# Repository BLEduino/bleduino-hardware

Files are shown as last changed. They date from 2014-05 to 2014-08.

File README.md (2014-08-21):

BLEduino Hardware
=================
Here you'll find all of the hardware design files related to the BLEduino and Shield-Shield.

* Bill of Materials - The full parts list used on the BLEduino and the Shield-Shield.
* Eagle - Schematic and PCB files for the BLEduino and Shield-Shield.
* Gerber - All of the Gerber files needed to produce your own BLEduinos or Shield-Shield.
* PDFs - PDF copies of the schematics and pcb including the individual layers.

These files are licensed under a [Creative Commons Attribution Share-Alike license](http://creativecommons.org/licenses/by-sa/2.5/).  That means you're allowed to modify, view, distribute, and remix any of the files for personal and comerical purposes as long as you credit the BLEduino and release your design files under the same or similar license.

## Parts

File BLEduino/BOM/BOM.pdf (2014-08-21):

# | Part | Q'ty | Description | Package | Pads | Mounting type | Vendor | Part No. | Brand | Descriptor

## BLEduino

1 | 3.3V Regulator | 1 | LP2985-33DBVR | SOT-23 | 5 | SMD | TI | 296-18476-1-ND | TI | U4
2 | 5V Regulator NCP1117-5 | 1 | NCP1117ST50T3G | SOT-223 | 4 | SMD | ON | NCP1117ST50T3GOSCT-ND | ON | U2
3 | 3x1 Male Headers | 1 | | 0.1" | 0 | SMD | | 929400E-01-03-ND | | JP4
4 | 1x14 Male Headers | 2 | | 0.1" | 0 | SMD | | 929400E-01-14-ND | | JP1, JP3
5 | Anti-Static Varistor | 2 | CG0603MLC-05E | 0603 | 2 | SMD | Bourns Inc. | CG0603MLC-05ECT-ND | Bourns Inc. | Z1, Z2
6 | ATMega32u4 | 1 | ATMEGA32U4-MU | QFN-44 | 45 | SMD | Atmel | ATMEGA32U4-MU-ND | Atmel | U1
7 | ATMega328P | 1 | ATMEGA328P-MUR | QFN-32 | 33 | SMD | Atmel | ATMEGA328P-MURCT-ND | Atmel | U3
8 | BLE Controller | 1 | NRF8001-R2Q32-T | QFN-32 | 33 | SMD | Nordic Semiconductor | 949-NRF8001-R2Q32-T | Nordic Semiconductor | NRF8001
9 | BALUN | 1 | 2450BM14A0002T | 0603 (6 pin) | 6 | SMD | Johanson Technology | 44W4473 | Johanson Technology | B1
10 | CAP 100n Ceramic | 10 | 0.1UF 25V 5% 0402->X7R | 0402 | 2 | SMD | | 587-1456-1-ND | | C1, C2, C6, C9, C10, C11, C18, C22, C30, C31
11 | CAP 15pF Ceramic | 4 | 15PF 16V 5% 0402->50V | 0402 | 2 | SMD | | 311-1017-1-ND | | C20, C21, C28, C29
12 | CAP 1nF Ceramic | 1 | 1000PF 10V 10% 0402->50V | 0402 | 2 | SMD | | 311-1036-1-ND | | C27
13 | CAP 1u Ceramic | 3 | 1UF 16V 10% 0402->10V X5R | 0402 | 2 | SMD | | 445-4978-1-ND | | C5, C4, C7
14 | CAP 1uF Ceramic | 2 | 1UF 16V 10% 0603->X5R | 0603 | 2 | SMD | | 311-1372-1-ND | | C16, C24
15 | CAP 2.2nF Ceramic | 1 | 2200PF 25V 5% 0402->50V X7R | 0402 | 2 | SMD | | 490-6359-1-ND | | C23
16 | CAP 22p Ceramic | 4 | 22PF 16V 5% 0402->0.25PF 50V | 0402 | 2 | SMD | | 311-1018-1-ND | | C12, C13, C32, C33
17 | CAP 22u Tantalum (Polarized) | 2 | CAP TANT 22UF 25V 1206->10V | 1206 | 2 | SMD | | 511-1465-1-ND | | C3, C14
18 | CAP 33nF Ceramic | 1 | 0.033UF 10V 10% 0402->16V | 0402 | 2 | SMD | | 1276-1555-1-ND | | C17
19 | CAP 2pF Ceramic | 1 | 2.0pF 10V 5% 0402->0.25PF 50V | 0402 | 2 | SMD | | | | C15
20 | IND 10uH | 1 | 10UH 50mA 5% 0603->10% | 0603 | 2 | SMD | | 445-3166-1-ND | | L5
21 | IND 15nH | 1 | 15NH 50mA %5 0402 | 0402 | 2 | SMD | Bourns Inc. | CI100505-15NJCT-ND | | L6
22 | Crystal 16MHz | 3 | CRYSTAL 16MHZ 20PF SMD | 3.20mm x 2.50mm | 4 | SMD | | CTX732CT-ND | | Y2, Y3, Y4
23 | Crystal 32,768KHz | 1 | CRYSTAL 32,768 KHZ 12.5PF SMD | 4.90mm x 1.80mm | 2 | SMD | | 535-9536-1-ND | | Y5
24 | Diode | 1 | DIODE 10V SOD-323 | SOD-323 | 2 | SMD | | 1N4148WS-FDICT-ND | | D1
25 | Ferrite Bead | 1 | MH2029-300YCT | 0805 | 2 | SMD | | MH2029-070YCT-ND | | L2
26 | LED Blue | 1 | BLUE ~470NM DIFFUSED 0603 ->BL-HB336A-TRB | 0603 | 2 | SMD | | 475-2816-1-ND | | BLE_CONN
27 | LED Green | 1 | GREEN ~570NM DIFFUSED 0603 ->BL-HG036D-AV-TRB | 0603 | 2 | SMD | | 516-1425-1-ND | | ON
28 | LED Yellow | 3 | YELLOW ~587NM DIFFUSED 0603->BL-H4036D-AV-TRB | 0603 | 2 | SMD | | 516-2856-1-ND | | RX, TX, L
29 | Level Converter BSS138 | 3 | BSS138-7-F | SOT-23 | 3 | SMD | Diodes Inc. | BSS138-FDICT-ND | Diodes Inc. | Q1, Q2, Q3
30 | P-FET PMV48XP | 2 | PMV48XP,215 | SOT-23 | 3 | SMD | NXP | 568-7579-1-ND | NXP | T1, T2
31 | PTC | 1 | MF-NSMF150-2 PTC 500mA | 1206 | 2 | SMD | | MF-NSMF050-2CT-ND | | F2
32 | RES 10K | 12 | 10K J 1/8W 0402->1/10W | 0402 | 2 | SMD | | P10KJCT-ND | | R1, R2, R4, R9, R12, R14, R18, R21, R22, R23, R24, R13
33 | RES 1K | 4 | 1K J 1/4W 0402->1/10W | 0402 | 2 | SMD | | P1.0KJCT-ND | | R5, R6, R7, R8,
34 | RES 4K7 | 1 | 4K7 (1/16W)0402 5% | | | | | | | R19
35 | RES 20K | 2 | 20K J 1/8W 0402->1/10W | 0402 | 2 | SMD | | P20KJCT-ND | | R16,R15
36 | RES 22 | 2 | 22R J 1/4W 0402->1/10W | 0402 | 2 | SMD | | P22JCT-ND | | R3, R10
37 | RES 22K | 1 | 22K J 1/8W 0402->1/10W | 0402 | 2 | SMD | | P22KJCT-ND | | R11
38 | RES 0 | 1 | 0 Ohm resistor 0402->1/10W | 0402 | 2 | SMD | | | | L1
39 | Small Push Button | 1 | SWITCH TACTILE KMR2 ->IPTG23K-Q-T/R | KMR221NG LFS | 4 | SMD | | CKN10246CT-ND | | RESET
40 | Micro USB Connector | 1 | 10118194-0001LF | | SMD - 5 Through -4 | SMD/Through-hole | FCI | 609-4618-1-ND | FCI | X2
41 | PCB | 1 | | | | | | 6L FR4 1.6mm Flash Gold -12 pcs per panel

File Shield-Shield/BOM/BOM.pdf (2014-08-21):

# | Part | Q'ty | Description | Package | Pads | Mounting type | Vendor | Part No. | Brand | Descriptor

## Shield-Shield

1 | x2 Elevated Headers #8 | 2 | Samtec Inc | ESW-108-33-T-S | POWER, IOL
2 | x1 Elevated Headers #10 | 1 | Samtec Inc | ESW-110-33-T-S | IOH
3 | x1 Elevated Headers #6 | 1 | Samtec Inc | ESW-106-33-T-S | AD
4 | x2 Regular Female Headers #14 | 2 | | PPTC141LFBN-RC | JP1, JP2
5 | 1x Push Button SMD | 1 | | FSM1LPATR | RESET
6 | 1x DC Jack | 1 | | PJ-102A | J1
7 | 1x Diode | 1 | | S2M-13-F | D1
8 | 1x SMD Switch | 1 | | JS202011SCQN | S1
9 | 1x SPI Male Headers 2x3 | 1 | | 67996-406HLF | ICSP
10 | PCB | 1

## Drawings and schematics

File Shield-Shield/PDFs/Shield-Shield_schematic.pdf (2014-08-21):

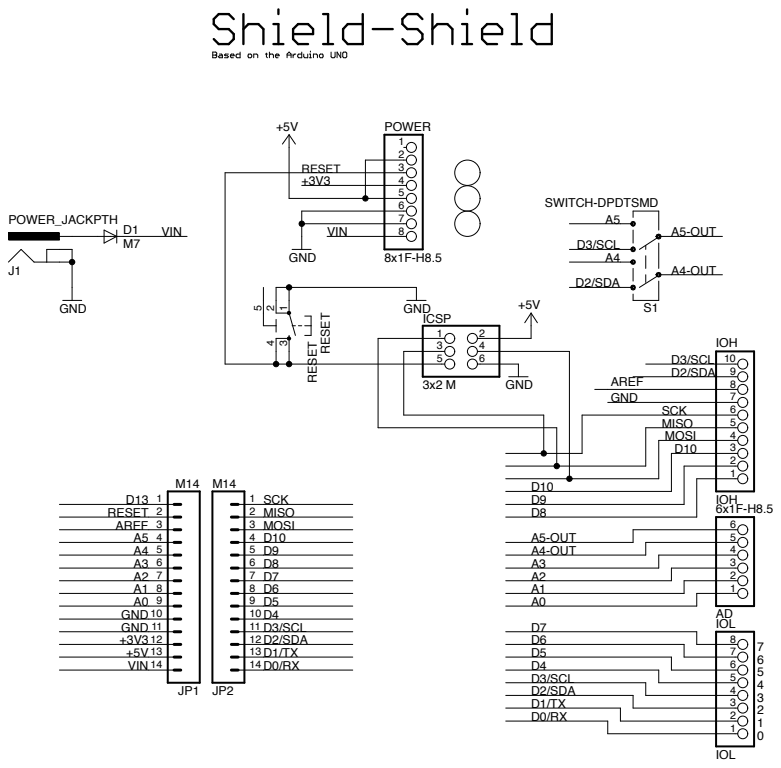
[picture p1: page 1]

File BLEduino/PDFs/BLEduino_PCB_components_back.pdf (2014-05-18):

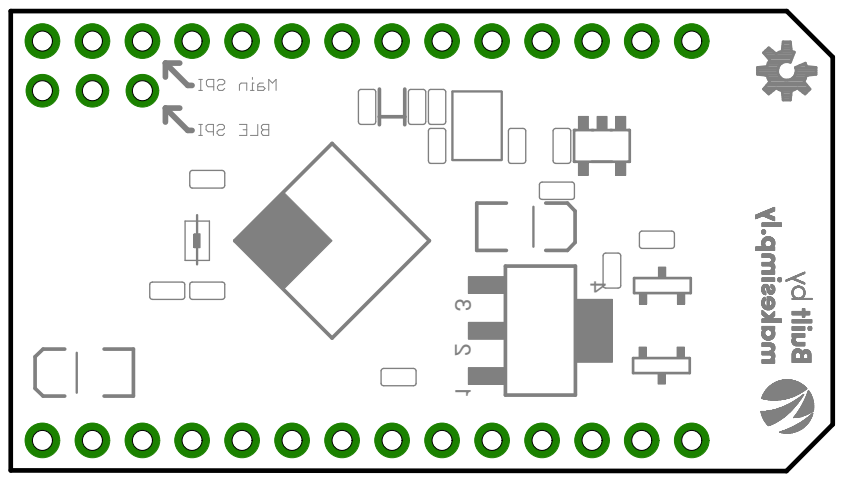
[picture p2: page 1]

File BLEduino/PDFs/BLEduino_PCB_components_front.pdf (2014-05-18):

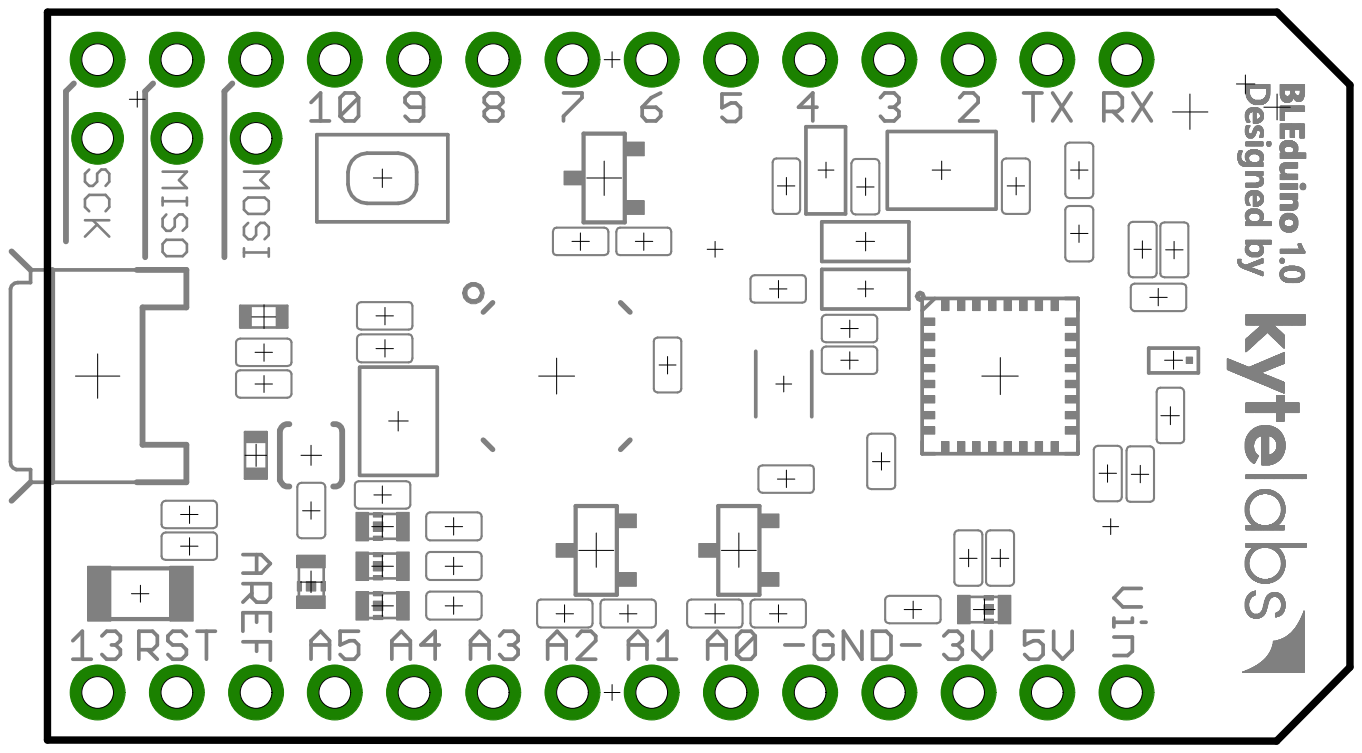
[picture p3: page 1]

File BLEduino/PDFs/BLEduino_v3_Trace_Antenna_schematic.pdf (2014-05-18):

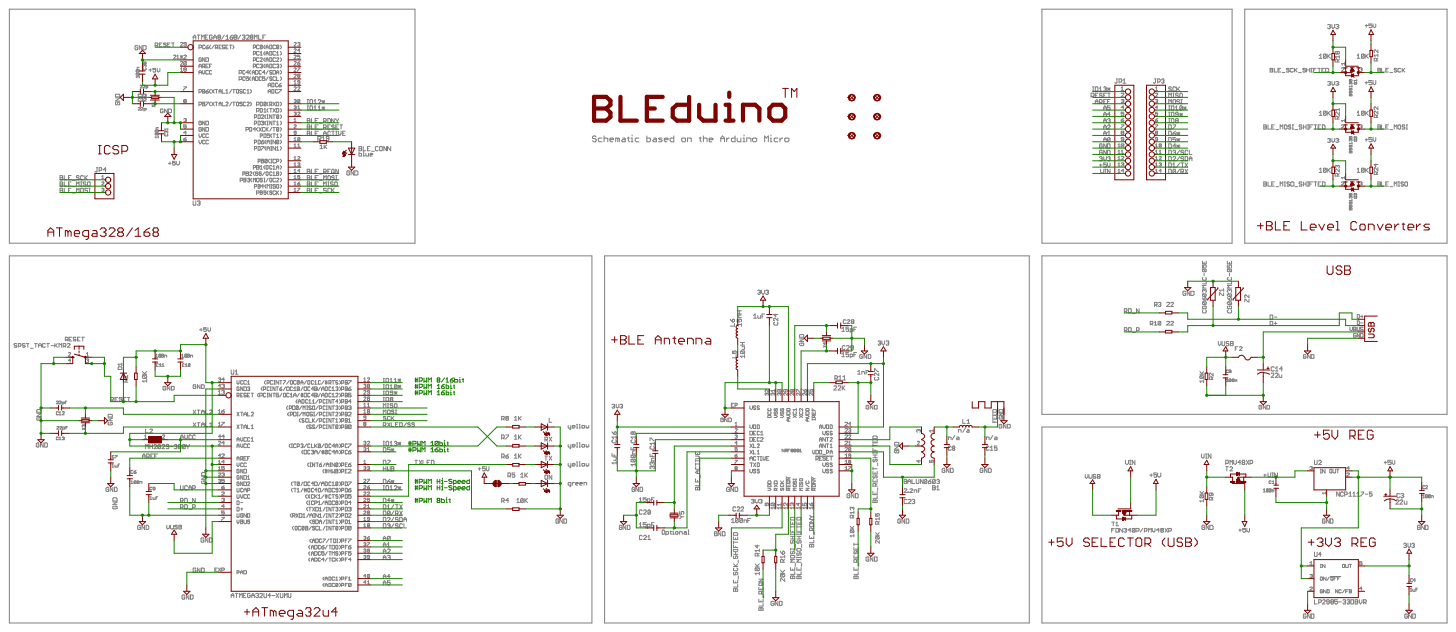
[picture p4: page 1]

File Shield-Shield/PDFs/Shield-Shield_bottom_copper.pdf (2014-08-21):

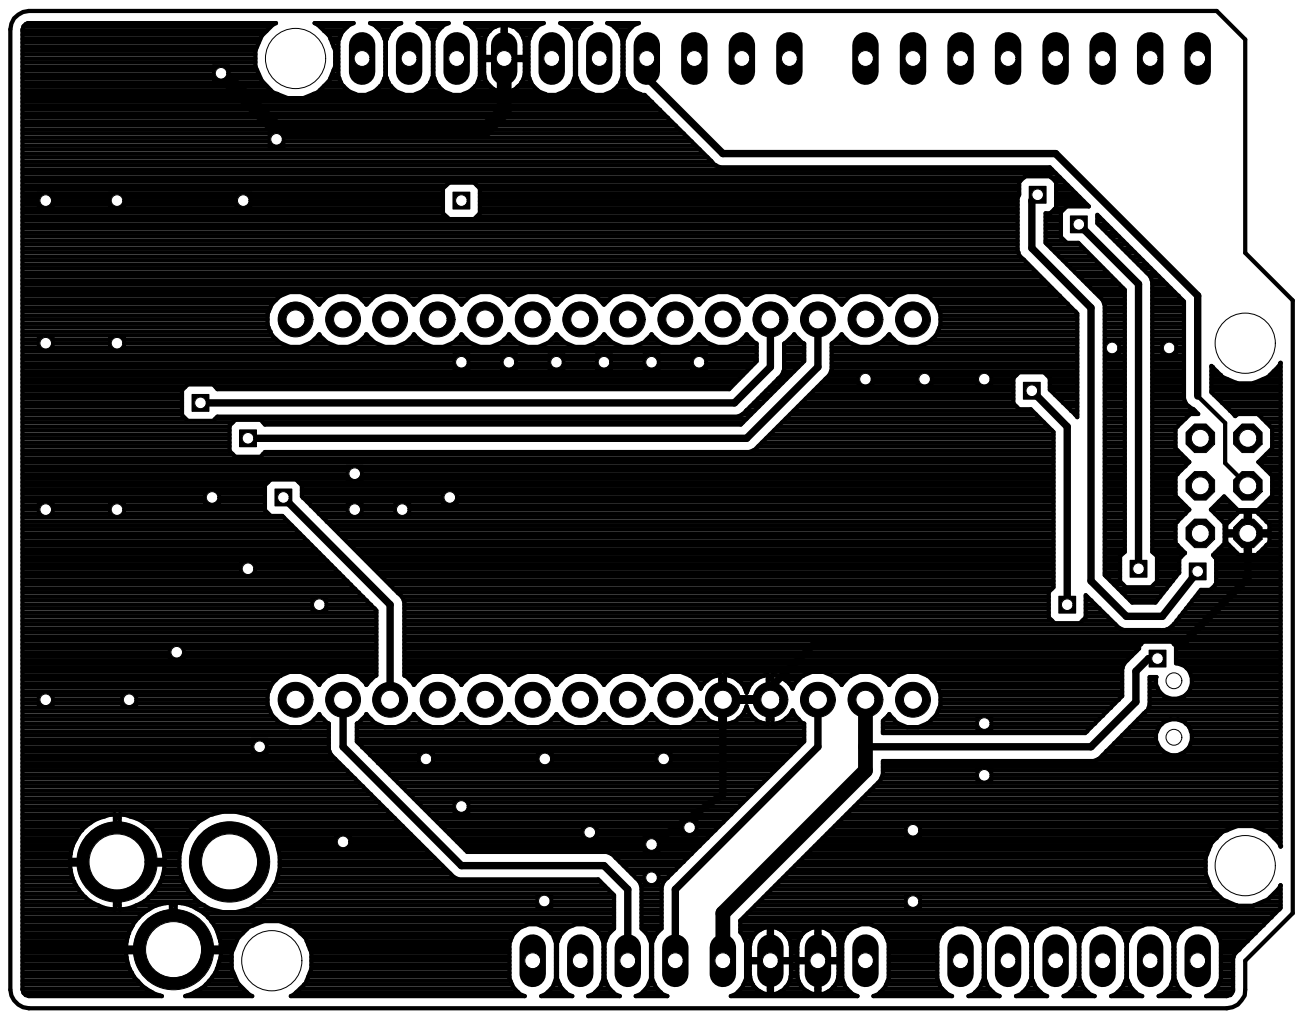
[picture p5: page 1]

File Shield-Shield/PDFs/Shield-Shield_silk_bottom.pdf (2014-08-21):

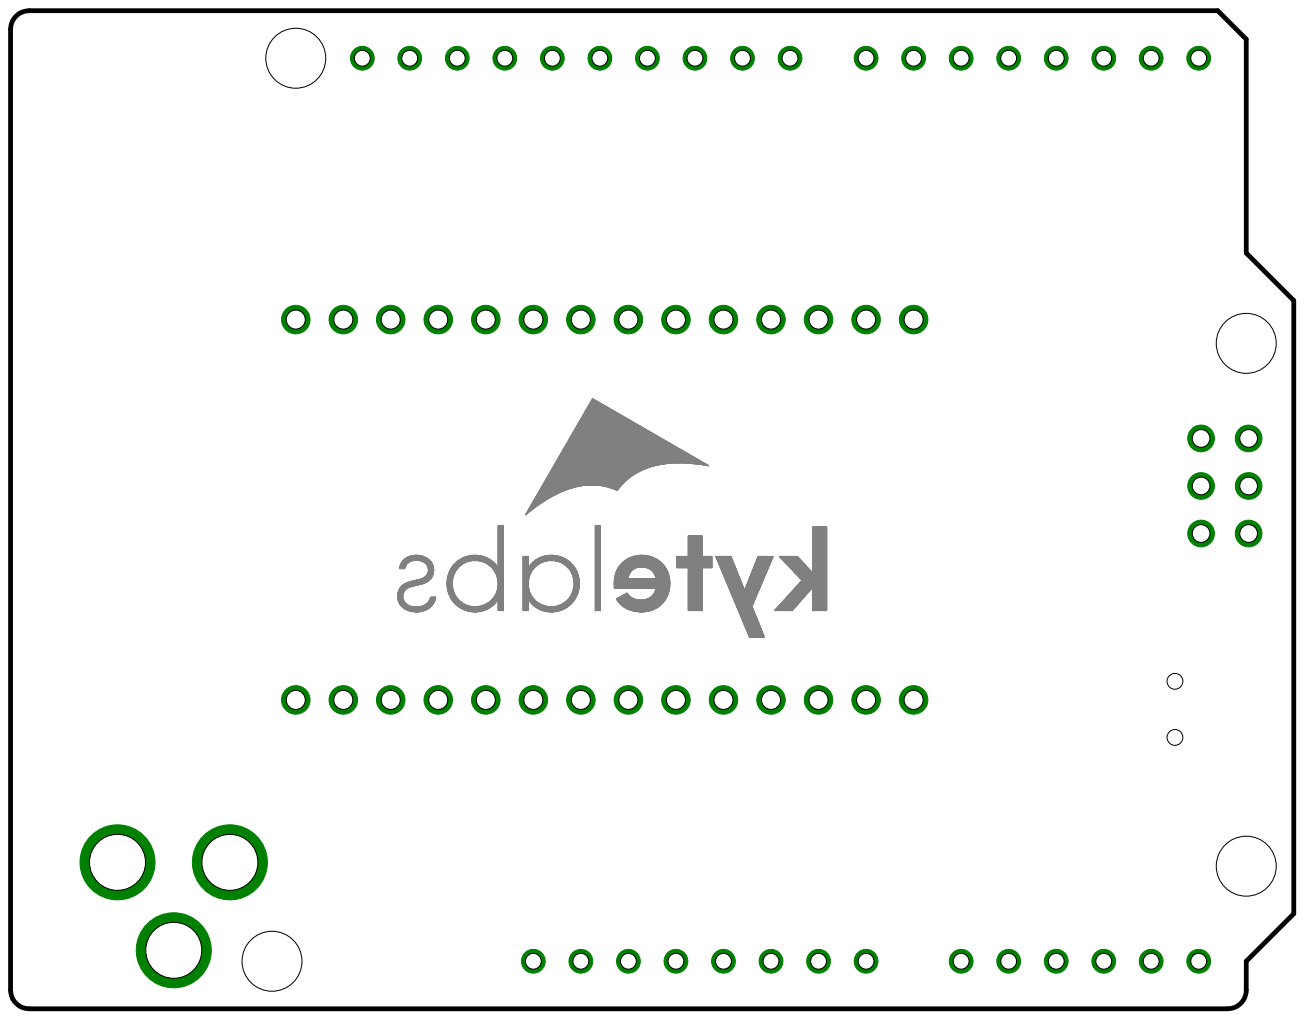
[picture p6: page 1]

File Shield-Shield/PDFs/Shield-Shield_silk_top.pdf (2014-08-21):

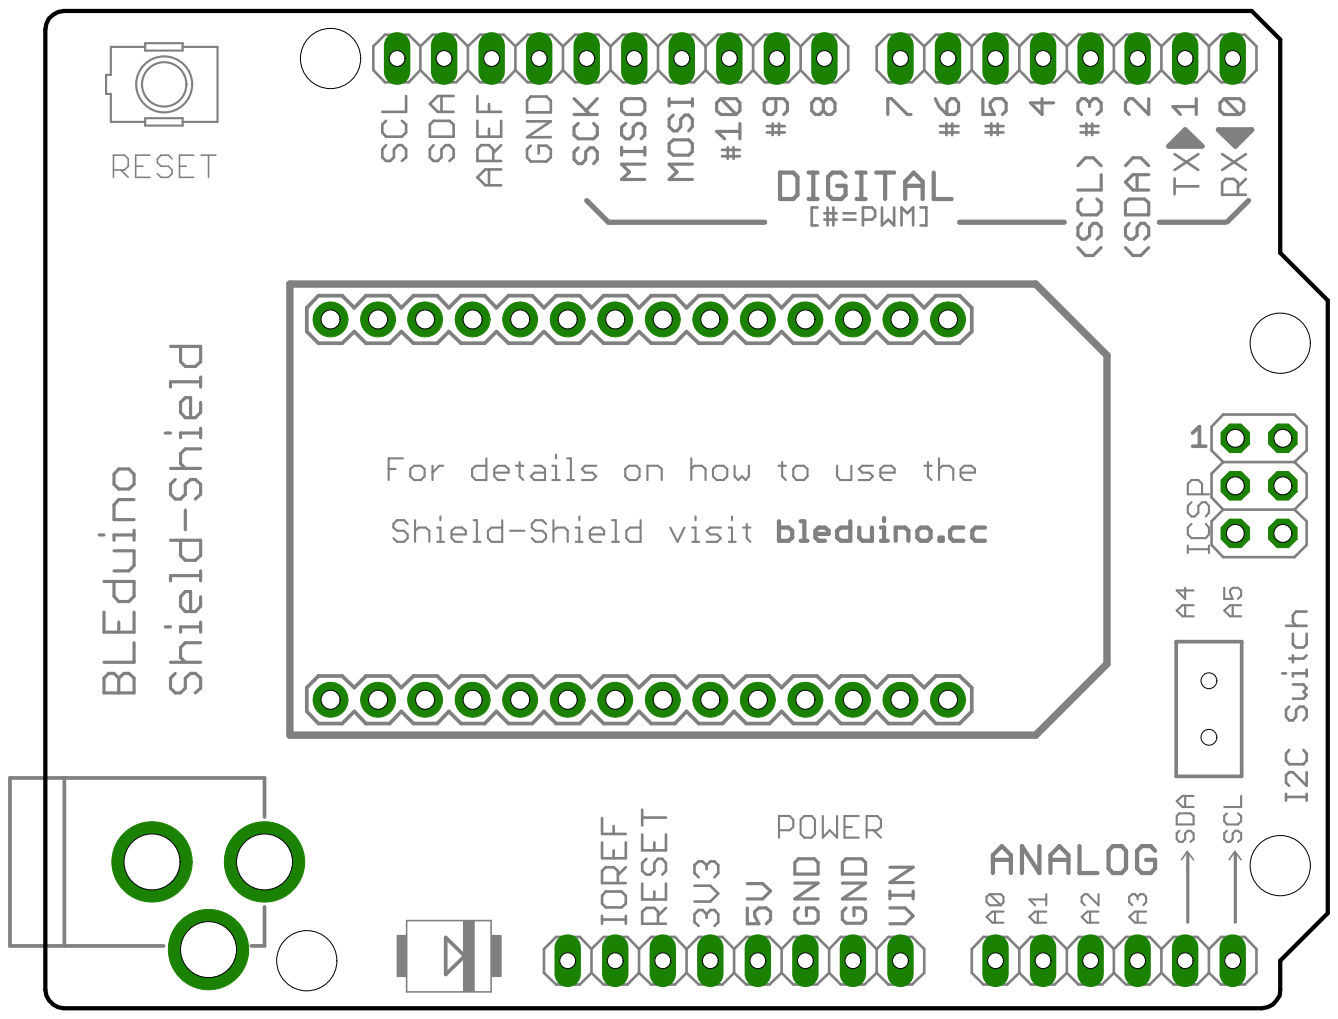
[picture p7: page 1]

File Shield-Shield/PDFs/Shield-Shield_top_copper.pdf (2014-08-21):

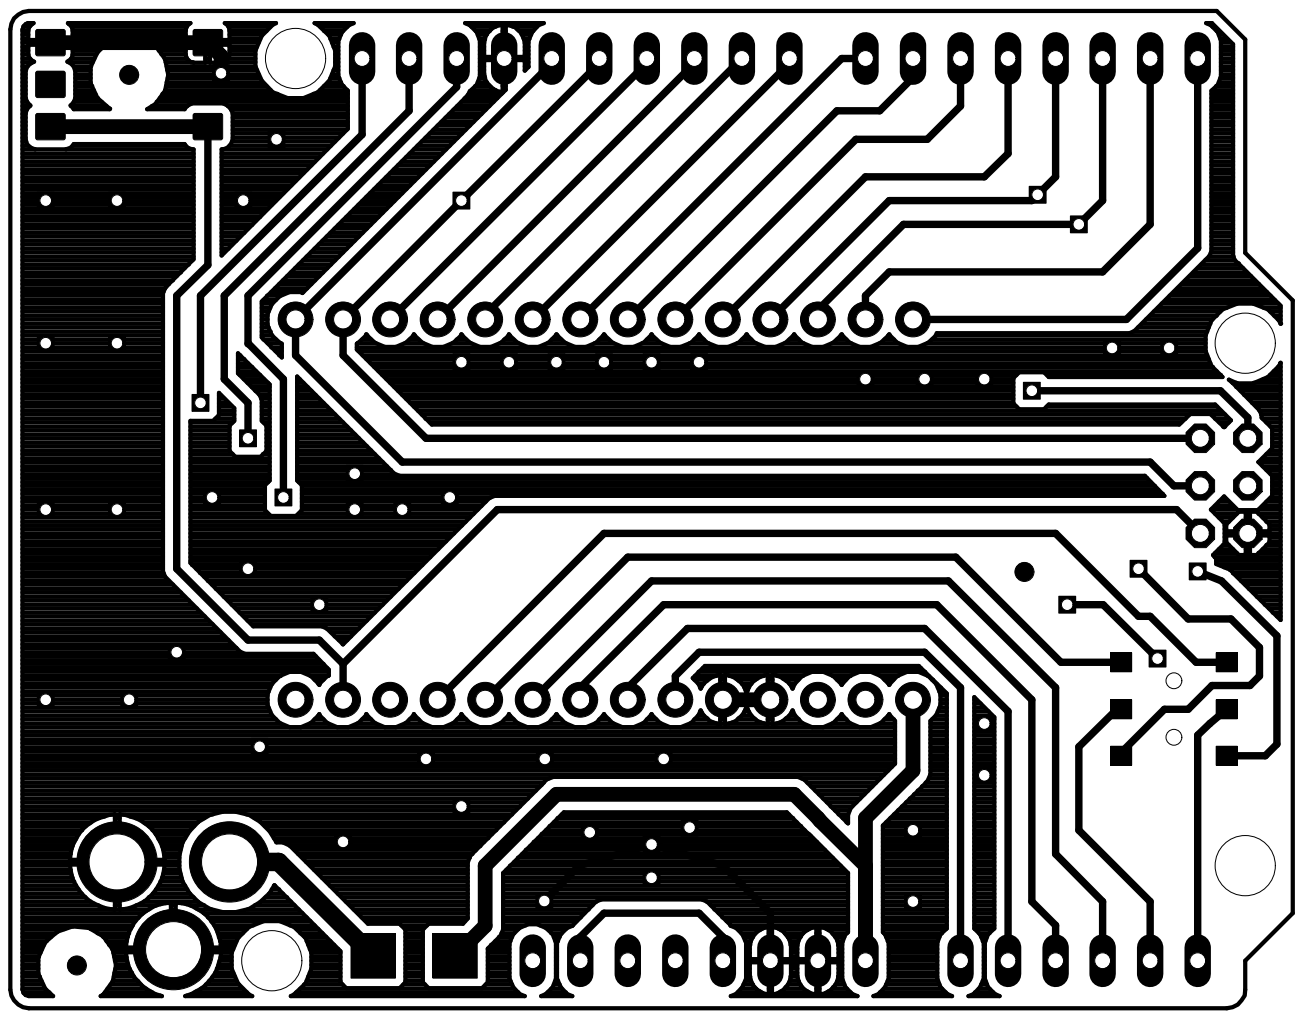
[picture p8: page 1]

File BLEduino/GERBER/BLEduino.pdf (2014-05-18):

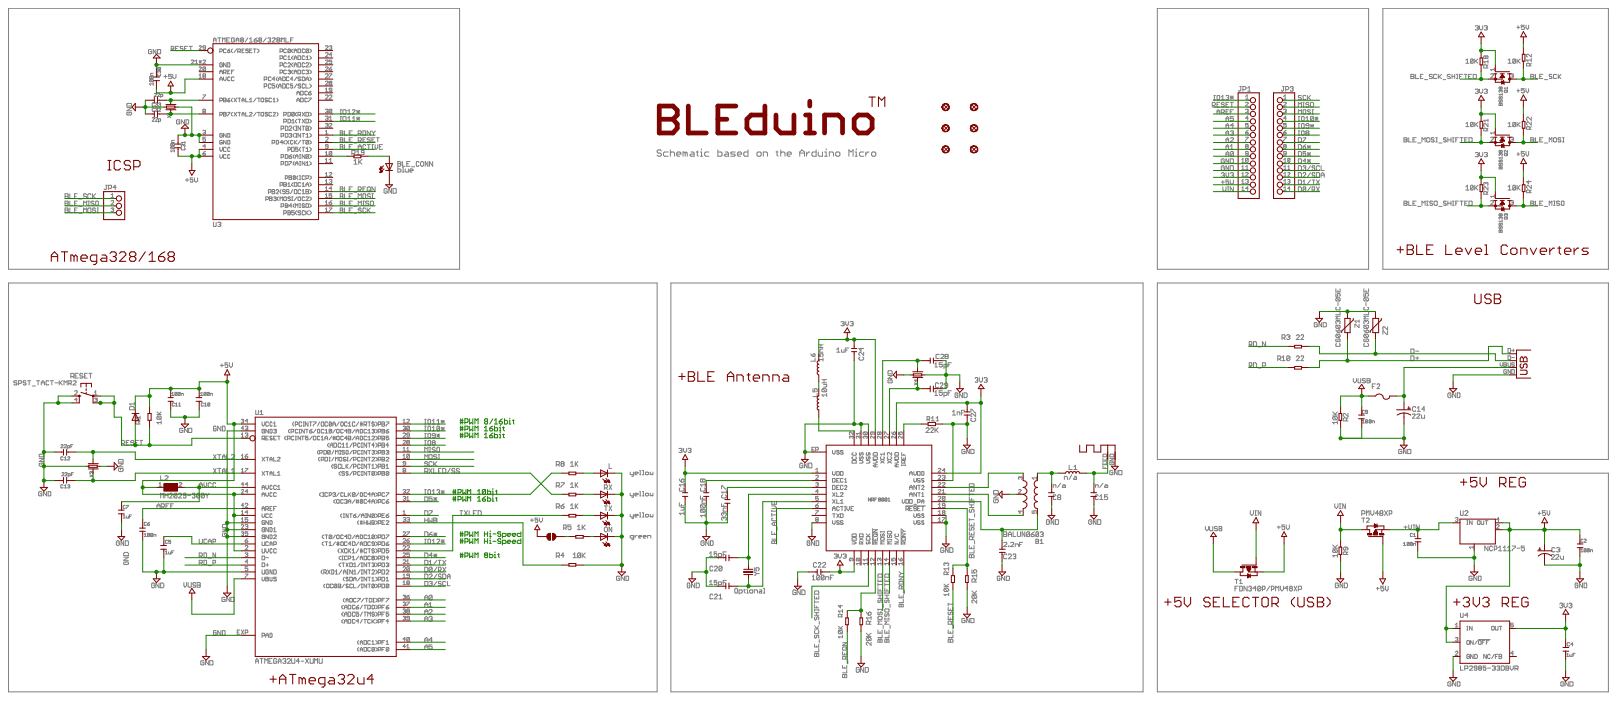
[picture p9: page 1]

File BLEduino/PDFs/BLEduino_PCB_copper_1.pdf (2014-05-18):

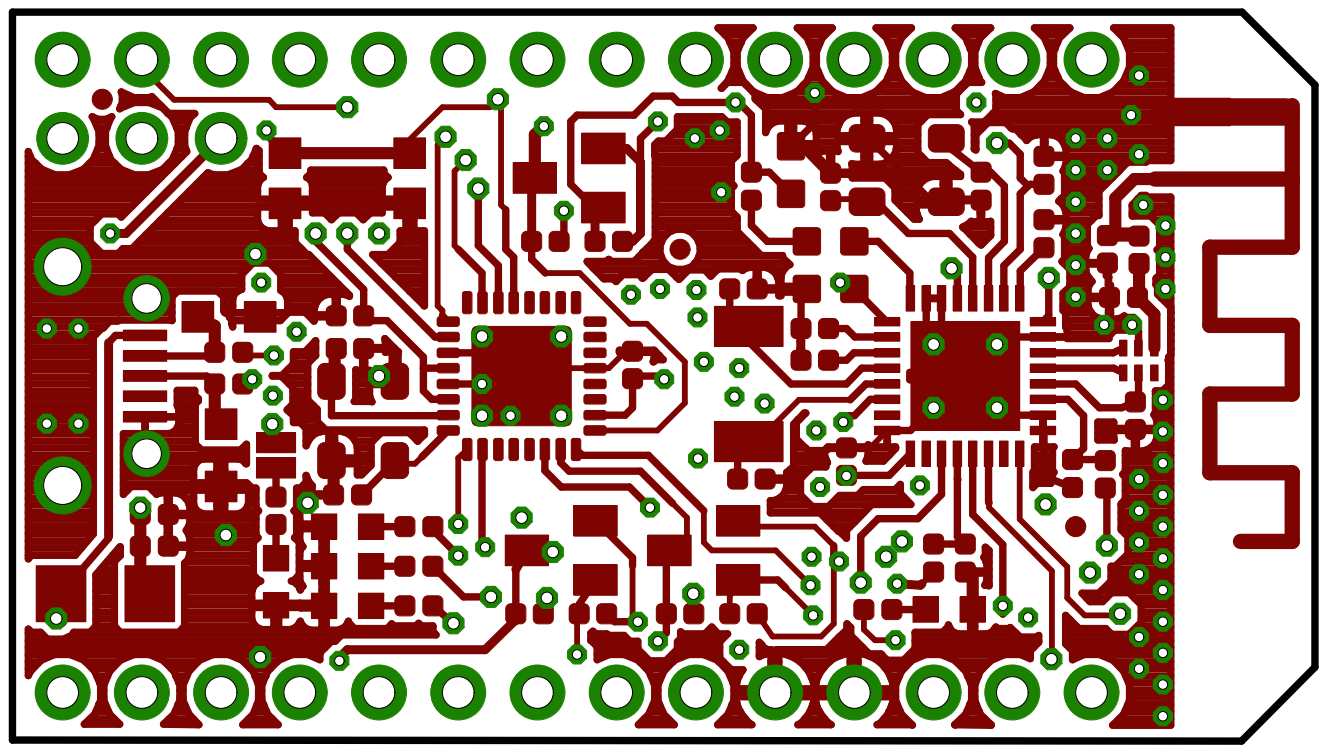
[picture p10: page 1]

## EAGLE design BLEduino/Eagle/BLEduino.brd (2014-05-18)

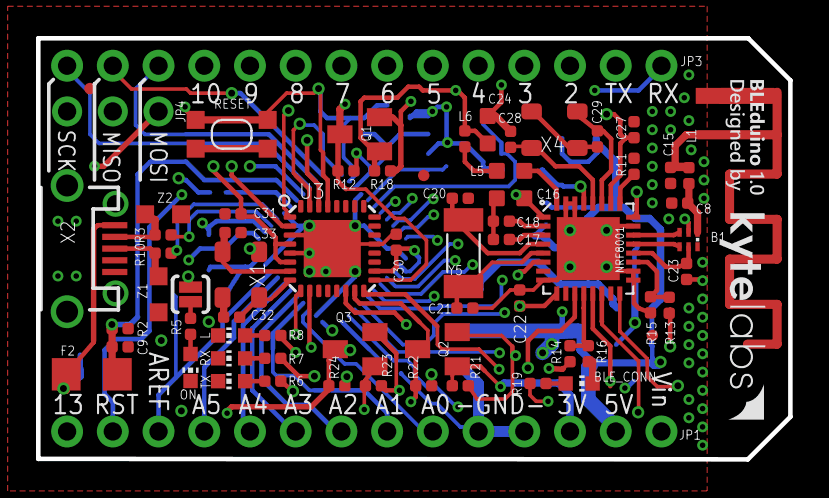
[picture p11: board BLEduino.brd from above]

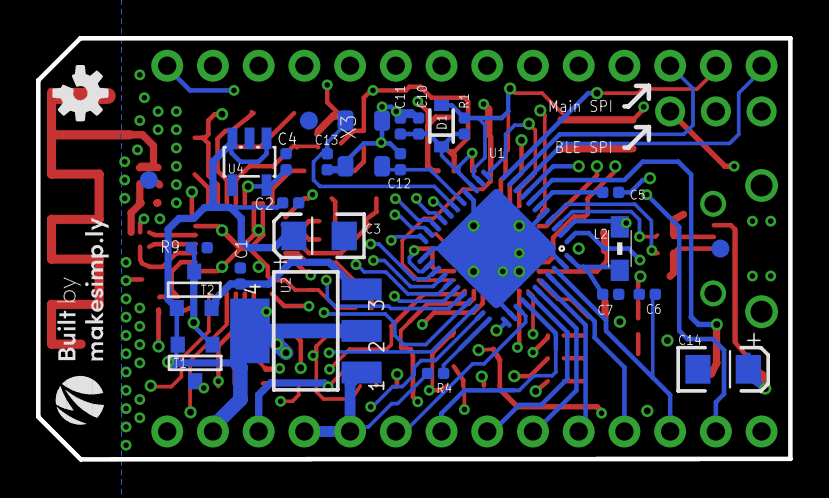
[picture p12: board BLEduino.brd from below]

Board: 6 copper layers, 41.8 x 23.4 mm, 96 parts (27 on the bottom side), 78 nets.

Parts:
ANT1: ANTENNA; RN-ANT
B1: BALUN0603; BALUN-0603
BLE_CONN: blue; CHIP-LED0603
C1, C2, C6, C9, C10, C11, C30, C31: 100n; C0402
C3, C14: 22u; EIA3216
C4, C5, C7: 1uF; C0402
C8, C15: n/a; C0402
C12, C13: 22pF; C0402
C16, C24: 1uF; C0603
C17: 33nF; C0402
C18, C22: 100nF; C0402
C20, C21, C28, C29: 15pF; C0402
C23: 2.2nF; C0402
C27: 1nF; C0402
C32, C33: 22p; C0402
D1: SOD-323
F2: R1206
JP1, JP3: 1X14-CB
JP2, JP5, JP6: FIDUCIALUFIDUCIAL; MICRO-FIDUCIAL
JP4: 1X03-CLEANBIG
L: yellow; CHIP-LED0603
L1: n/a; L0402
L2: MH2029-300Y; 0805
L5: 10uH; L0603
L6: 15nH; L0402
LOGO_BOTTOM: OSHW-LOGO-S
LOGO_TOP: V3_KYTELABS_TOP
NRF8001: FITNESSDEVICE_NRF8001; FITNESSDEVICE_QFN-32
ON: green; CHIP-LED0603
Q1, Q2, Q3: BSS138; SOT23
R1, R2, R4, R9, R12, R13, R14, R18, R21, R22, R23, R24: 10K; R0402
R3, R10: 22; R0402
R5, R6, R7, R8, R19: 1K; R0402
R11: 22K; R0402
R15, R16: 20K; R0402
RESET: SPST_TACT-KMR2; KMR2
RX: yellow; CHIP-LED0603
SILK_2: V3_MAKESIMPLY_BOTTOM
SJ1: SOLDERJUMPERNC2; SJ_2S-NOTRACE
T1: FDN340P/PMV48XP; SOT-23
T2: PMV48XP; SOT-23
TX: yellow; CHIP-LED0603
U1: ATMEGA32U4-XUMU; QFN44ML7X7
U2: NCP1117-5; LINEAR_SOT223
U3: ATMEGA8/168/328MLF; MLF32X-W/HEAT
U4: LP2985-33DBVR; SOT23-DBV
U$28, U$29, U$53: FIDUCIAL1X2; FIDUCIAL-1X2
X1, X3, X4: 4P-SMD-3.2X2.5
X2: SPARKFUN_USB-MICROB
Y5: Y5; FITNESSDEVICE_CRYSTAL-ABS10
Z1, Z2: CG0603MLC-05E; CT/CN0603

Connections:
3V3: C4.1, C16.1, C22.2, C24.1, C27.1, JP1.12, L6.2, NRF8001.1, NRF8001.9, NRF8001.24, NRF8001.26, NRF8001.29, Q1.1, Q2.1, Q3.1, R18.2, R21.2, R23.2, U4.5
+5V: C2.1, C3.A, C10.1, C11.1, C30.1, C31.1, D1.1, JP1.13, L2.1, R1.1, R12.1, R22.1, R24.1, SJ1.1, T1.2, T2.3, U1.2, U1.14, U1.24, U1.34, U2.2, U2.4, U3.4, U3.6, U3.18, U4.1, U4.3
+VIN: C1.1, T2.2, U2.3
A0: JP1.9, U1.36
A1: JP1.8, U1.37
A2: JP1.7, U1.38
A3: JP1.6, U1.39
A4: JP1.5, U1.40
A5: JP1.4, U1.41
AREF: C6.1, JP1.3, U1.42
AVCC: C7.1, L2.2, U1.44
BLE_ACTIVE: NRF8001.6, U3.9
BLE_MISO: JP4.2, Q3.3, R24.2, U3.16
BLE_MISO_SHIFTED: NRF8001.14, Q3.2, R23.1
BLE_MOSI: JP4.3, Q2.3, R22.2, U3.15
BLE_MOSI_SHIFTED: NRF8001.13, Q2.2, R21.1
BLE_RDNY: NRF8001.16, U3.1
BLE_REQN: R14.1, U3.14
BLE_REQN_SHIFTED: NRF8001.12, R14.2, R16.2
BLE_RESET: R13.1, U3.2
BLE_RESET_SHIFTED: NRF8001.19, R13.2, R15.2
BLE_SCK: JP4.1, Q1.3, R12.2, U3.17
BLE_SCK_SHIFTED: NRF8001.11, Q1.2, R18.1
D0/RX: JP3.14, U1.20
D1/TX: JP3.13, U1.21
D2/SDA: JP3.12, U1.19
D3/SCL: JP3.11, U1.18
D4*: JP3.10, U1.25
D5*: JP3.9, U1.31
D6*: JP3.8, U1.27
D7: JP3.7, U1.1
D+: R10.2, X2.D+, Z1.1
D-: R3.2, X2.D-, Z2.1
GND: ANT1.GND, B1.2, BLE_CONN.C, C1.2, C2.2, C3.C, C4.2, C5.2, C6.2, C7.2, C8.2, C9.2, C10.2, C11.2, C12.1, C13.1, C14.C, C15.2, C16.2, C17.2, C18.2, C20.2, C21.2, C22.1, C23.1, C24.2, C27.2, C28.2, C29.2, C30.2, C31.2, C32.2, C33.2, JP1.10, JP1.11, L.C, NRF8001.8, NRF8001.17, NRF8001.18, NRF8001.23, NRF8001.30, NRF8001.31, NRF8001.EP, ON.C, R2.1, R4.2, R9.1, R11.2, R15.1, R16.1, RESET.2, RESET.4, RX.C, TX.C, U1.5, U1.15, U1.23, U1.35, U1.43, U1.EXP, U2.1, U3.3, U3.5, U3.21, U3.HEAT, U4.2, X1.1, X1.3, X2.GND, X3.1, X3.3, X4.1, X4.3, Z1.2, Z2.2
HWB: R4.1, U1.33
IO8: JP3.6, U1.28
IO9*: JP3.5, U1.29
IO10*: JP3.4, U1.30
IO11*: U1.12, U3.31
IO12*: U1.26, U3.30
IO13*: JP1.1, R8.1, U1.32
MISO: JP3.2, U1.11
MOSI: JP3.3, U1.10
unnamed: C33.1, U3.7, X1.4
unnamed: R7.2, RX.A
unnamed: ON.A, R5.2
unnamed: R6.2, TX.A
unnamed: C32.1, U3.8, X1.2
unnamed: R19.2, U3.10
unnamed: L.A, R8.2
unnamed: BLE_CONN.A, R19.1
unnamed: ANT1.FEED, C15.1, L1.2
unnamed: C18.1, NRF8001.2
unnamed: R5.1, SJ1.2
unnamed: L5.1, NRF8001.32
unnamed: L5.2, L6.1
unnamed: C17.1, NRF8001.3
unnamed: C20.1, NRF8001.4, Y5.P$1
unnamed: C21.1, NRF8001.5, Y5.P$2
unnamed: B1.5, C23.2, NRF8001.20
unnamed: B1.3, NRF8001.22
unnamed: B1.4, NRF8001.21
unnamed: B1.1, C8.1, L1.1
unnamed: NRF8001.25, R11.1
unnamed: C28.1, NRF8001.28, X4.4
unnamed: C29.1, NRF8001.27, X4.2
RD_N: R3.1, U1.3
RD_P: R10.1, U1.4
RESET: D1.2, JP1.2, R1.2, RESET.1, RESET.3, U1.13, U3.29
RXLED/SS: R7.1, U1.8
SCK: JP3.1, U1.9
TXLED: R6.1, U1.22
UCAP: C5.1, U1.6
VIN: JP1.14, R9.2, T1.3, T2.1
VUSB: C9.1, F2.1, R2.2, T1.1, U1.7
VUSBD: C14.A, F2.2, X2.VBUS
XTAL1: C13.2, U1.17, X3.2
XTAL2: C12.2, U1.16, X3.4

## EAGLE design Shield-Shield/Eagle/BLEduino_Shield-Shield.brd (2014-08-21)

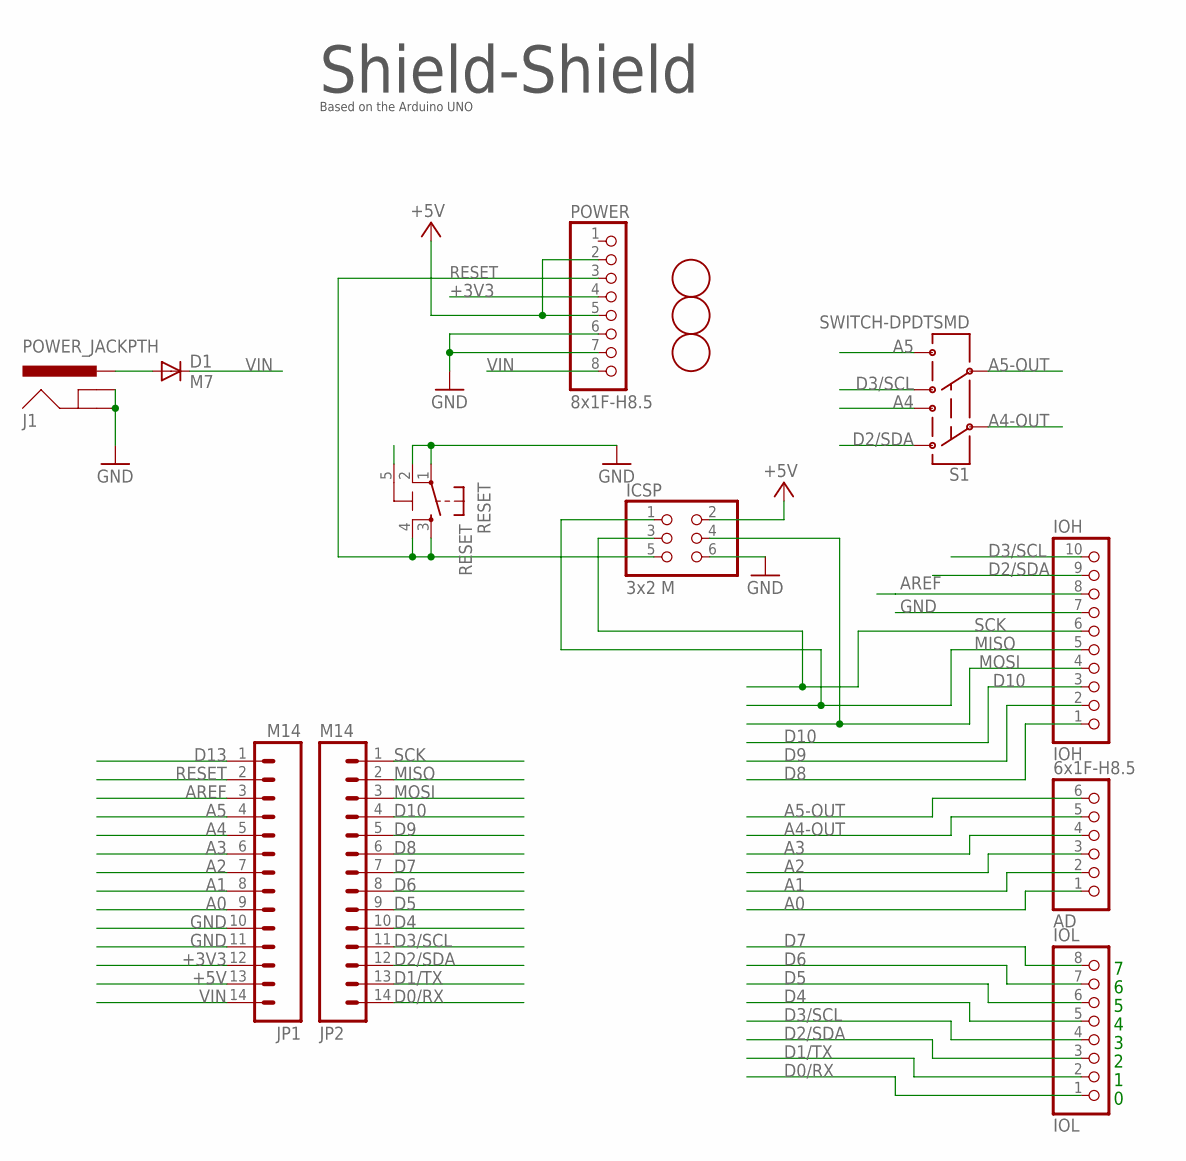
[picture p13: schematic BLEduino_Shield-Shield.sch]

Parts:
AD: 6x1F-H8.5; 1X06
D1: M7; SMB
FD1, FD2, FD3: FIDUCIALMOUNT; FIDUCIA-MOUNT
ICSP: 3x2 M; 2X03
IOH: IOH; 1X10
IOL: IOL; 1X08
J1: POWER_JACKPTH; POWER_JACK_PTH
JP1, JP2: M14; 1X14
POWER: 8x1F-H8.5; 1X08
RESET: RESET; TS42
S1: SWITCH-DPDTSMD; AYZ0202

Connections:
+3V3: JP1.12, POWER.4
+5V: ICSP.2, JP1.13, POWER.2, POWER.5
A0: AD.1, JP1.9
A1: AD.2, JP1.8
A2: AD.3, JP1.7
A3: AD.4, JP1.6
A4: JP1.5, S1.3
A4-OUT: AD.5, S1.2
A5: JP1.4, S1.6
A5-OUT: AD.6, S1.5
AREF: IOH.8, JP1.3
D0/RX: IOL.1, JP2.14
D1/TX: IOL.2, JP2.13
D2/SDA: IOH.9, IOL.3, JP2.12, S1.1
D3/SCL: IOH.10, IOL.4, JP2.11, S1.4
D4: IOL.5, JP2.10
D5: IOL.6, JP2.9
D6: IOL.7, JP2.8
D7: IOL.8, JP2.7
D8: IOH.1, JP2.6
D9: IOH.2, JP2.5
D10: IOH.3, JP2.4
D13: JP1.1
GND: ICSP.6, IOH.7, J1.GND, J1.GNDBREAK, JP1.10, JP1.11, POWER.6, POWER.7, RESET.1, RESET.2
MISO: ICSP.1, IOH.5, JP2.2
MOSI: ICSP.4, IOH.4, JP2.3
unnamed: D1.A, J1.PWR
RESET: ICSP.5, JP1.2, POWER.3, RESET.3, RESET.4
SCK: ICSP.3, IOH.6, JP2.1
VIN: D1.C, JP1.14, POWER.8

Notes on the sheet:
Shield-Shield
Based on the Arduino UNO

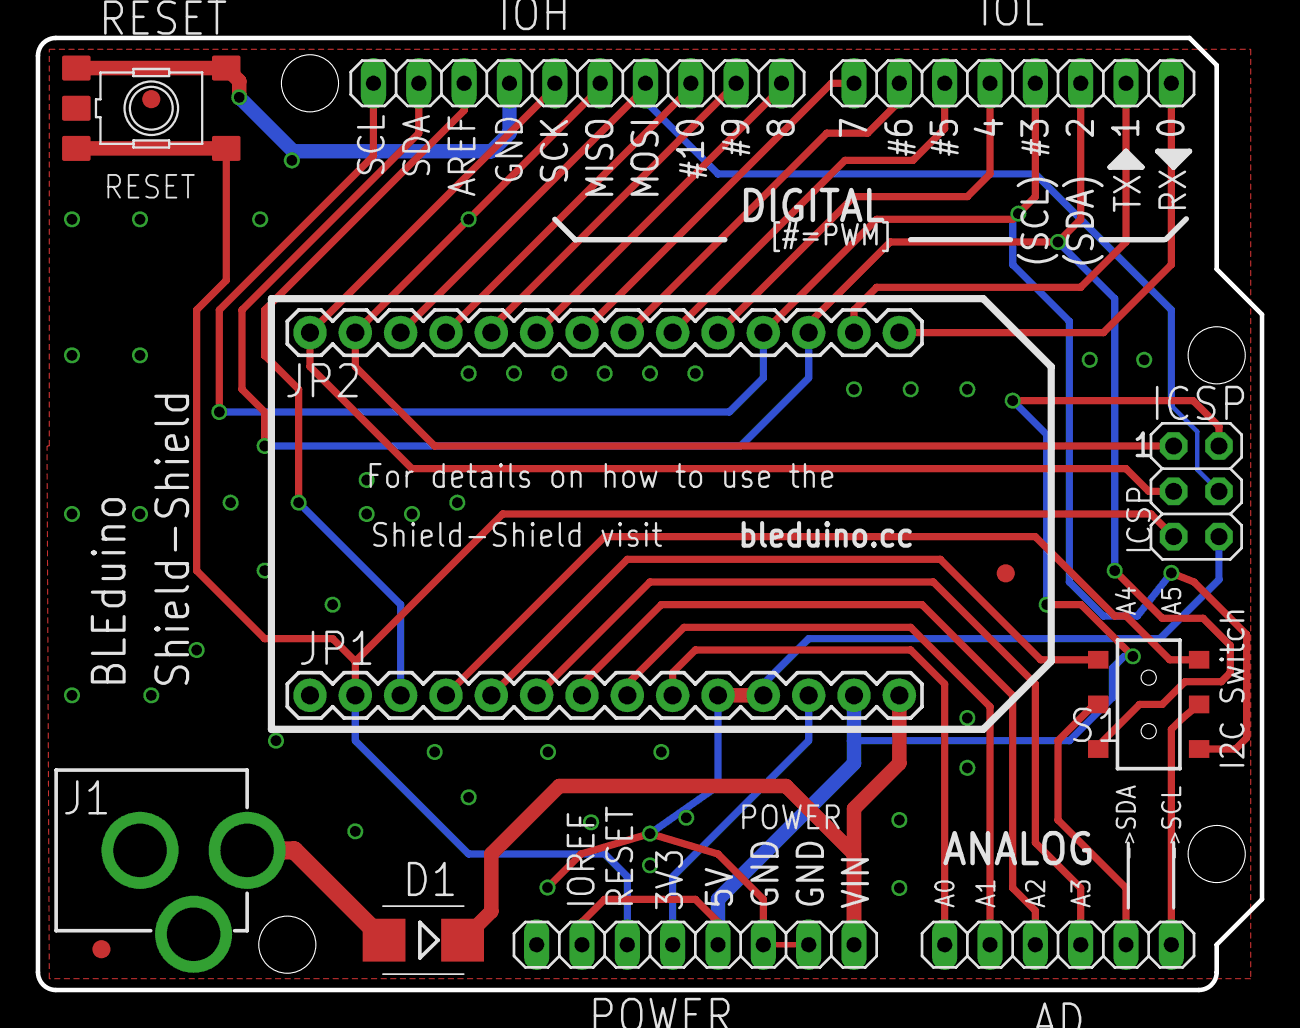
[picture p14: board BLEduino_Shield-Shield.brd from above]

Board: 4 copper layers, 68.6 x 53.3 mm, 15 parts (1 on the bottom side), 29 nets.

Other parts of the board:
U$1: KYTELABS_LOGO_BIG

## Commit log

2013-09-30 First hardware source commit.
    All the hardware source files or the BLEduino. Needs a few minor
    changes.
    [BLEduino.brd, BLEduino.sch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]
2013-10-01 Added some missing info in the BOM
    [BOM.xlsx, Final Parts List.xlsx]
2013-10-08 Antenna was missing, added it.
    [BOM.xlsx]
2013-11-02 Updated BOM
    [BOM.xlsx]
2013-11-02 Updated BOM with necessary manufacturing details
    [BOM.xlsx]
2013-11-16 Updated design files and BOM with the latest 6-layered board
    [BLEduino.brd, BLEduino.sch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]
2014-01-11 Final BLEduino Hardware Files
    [BLEduino.brd, BLEduino.sch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]
2014-01-11 Changed some file names.
    [BLEduino.GBL, BLEduino.GBO, BLEduino.GBP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]
2014-05-18 Latest BLEduino Files
    Should be the same as the BLEduino that will ship.
    [BLEduino.GBL, BLEduino.GBO, BLEduino.GBP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]
2014-08-20 BOM Update
    Fixed a few errors in the BOM and made it more readable. Also uploaded
    it in PDF for convenience.
    [BOM.xlsx]
2014-08-21 Merged BLEduino repository with Shield-Shield repository.
    [BLEduino.GBL, BLEduino.GBO, BLEduino.GBP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]
2014-10-24 Fixed BOM Crystal Labels
    Pointed out by forum user “christine_le”.
    [BOM.xlsx]

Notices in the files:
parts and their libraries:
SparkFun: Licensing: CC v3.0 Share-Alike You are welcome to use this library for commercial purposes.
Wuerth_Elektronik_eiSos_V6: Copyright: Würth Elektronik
